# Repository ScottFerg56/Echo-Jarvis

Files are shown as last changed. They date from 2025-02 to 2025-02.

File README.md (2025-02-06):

# Echo Jarvis
Converting an Amazon Echo Dot housing to contain an ESPHome implementation of Home Assistant voice assist using an ESP32 processor and other electronics devices from Adafruit.
Named after the "Hey Jarvis" wakeword. This is **NOT** a reverse engineering hack of the Echo circuit boards or software, just a repurposing of the sphere housing to contain
several Adafruit electronics parts brought together to make an IoT device for home automation and control. Many others have accomplished the same functionality, housed in
a utilitarian if not aesthetically pleasing 3D-printed box. I wanted something a bit more novel and fun!

## The disassembled Echo Dot:
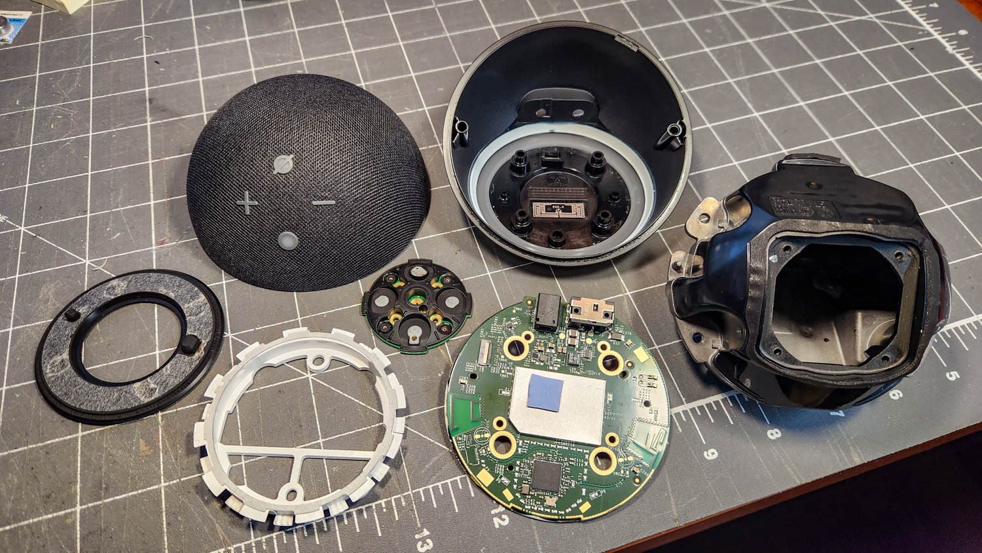
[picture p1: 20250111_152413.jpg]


## Replacement guts:
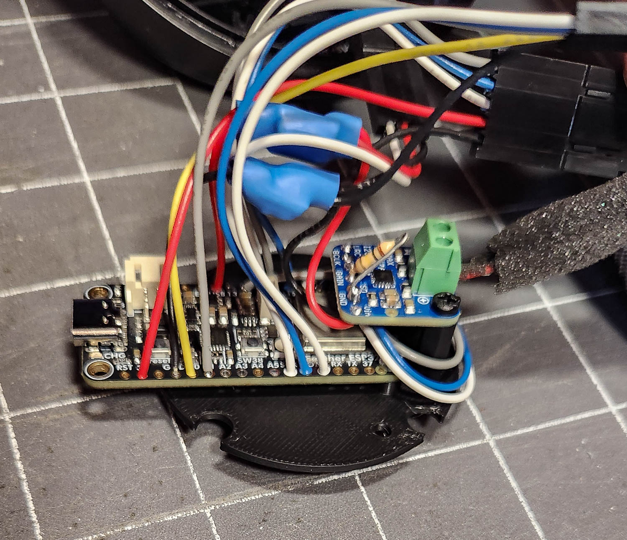
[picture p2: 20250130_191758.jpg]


## The Gallery:
More images and build details are in my [project gallery](https://scottferguson.smugmug.com/Projects/Echo-Jarvis).

## Files:
This project includes the following files:
* Fusion 360 (F3D) files and 3D-printable OBJ files for the button plate and processor mount base plate.
* A spreadsheet with wiring details and parts list with links.
* An image of the wiring details for the processor.
* The YAML file for creating the ESPHome device. This is very basic, but provides a sweet little mechanism for
volume control borrowed from another ESPHome user. (Credits in the file.)

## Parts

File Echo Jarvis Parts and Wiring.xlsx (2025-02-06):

Wiring:
 |  |  | mic 3V
mic GND | neo GND | sw GND | Amp GND
 | Ø | yellow | sw 0
 | O | gray | sw 1
 |  |  |  |  | neo PWR | amp VIN
 |  |  |  |  | amp LRC | gray | strapping
strapping |  |  |  |  | mic DOUT | white
strapping |  |  | neo data |  | mic LRCL | gray
 | + | blue | sw 2 |  | mic BCLK | blue | strapping
 | - | white | sw 3 |  | amp DIN | white
 |  |  |  |  | amp BCLK | blue
Parts:
Adafruit ESP32 Feather V2 (https://www.adafruit.com/product/5400)
Adafruit I2S 3W Class D Amplifier Breakout - MAX98357A (https://www.adafruit.com/product/3006)
Adafruit I2S MEMS Microphone Breakout - SPH0645LM4H (https://www.adafruit.com/product/3421)
Tactile Switch SPST-NO Top Actuated Surface Mount (https://www.digikey.com/en/products/detail/panasonic-electronic-components/EVQ-PPBA25/259539) |  |  |  | no longer manufactured, but equivalent alternatives may exist

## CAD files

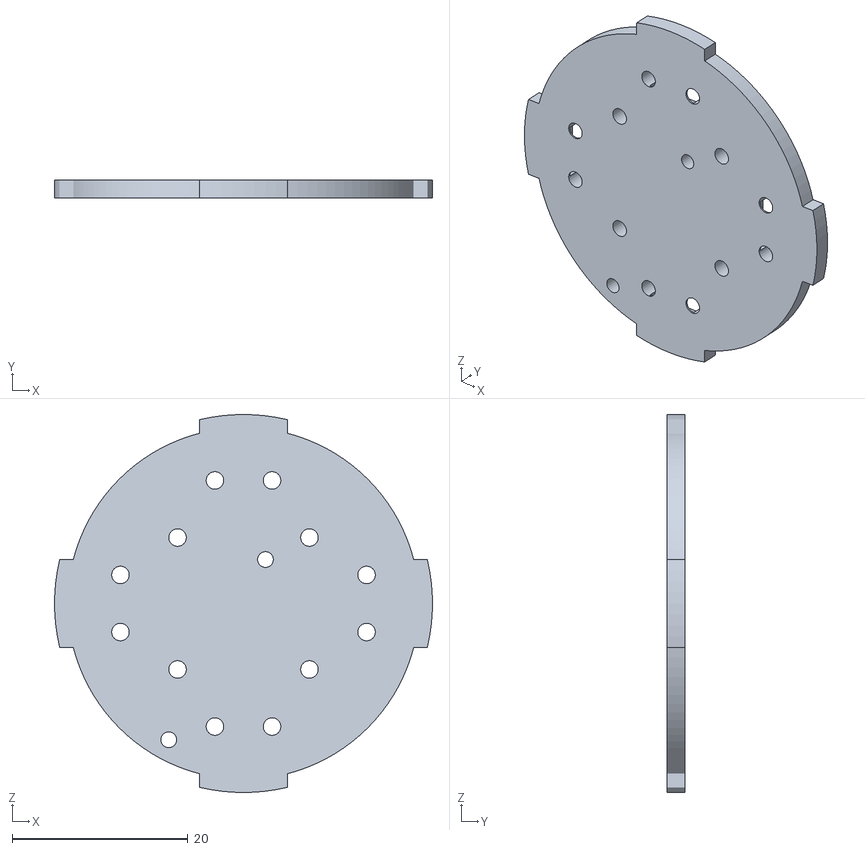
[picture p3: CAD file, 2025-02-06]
Button Plate.obj
43.0 x 2.00 x 43.0

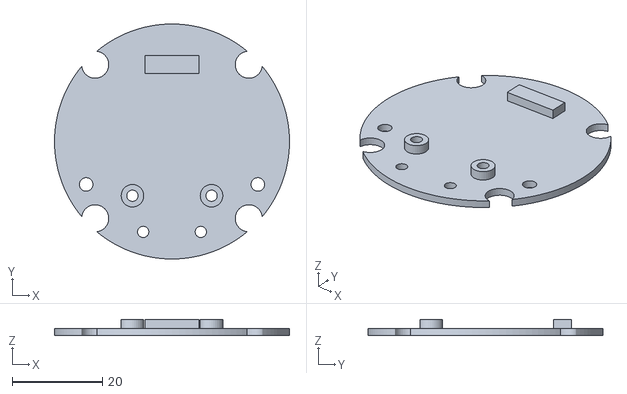
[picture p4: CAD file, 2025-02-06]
Base Plate.obj
52.0 x 52.0 x 3.60

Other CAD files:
Base Plate.f3d
Button Plate.f3d

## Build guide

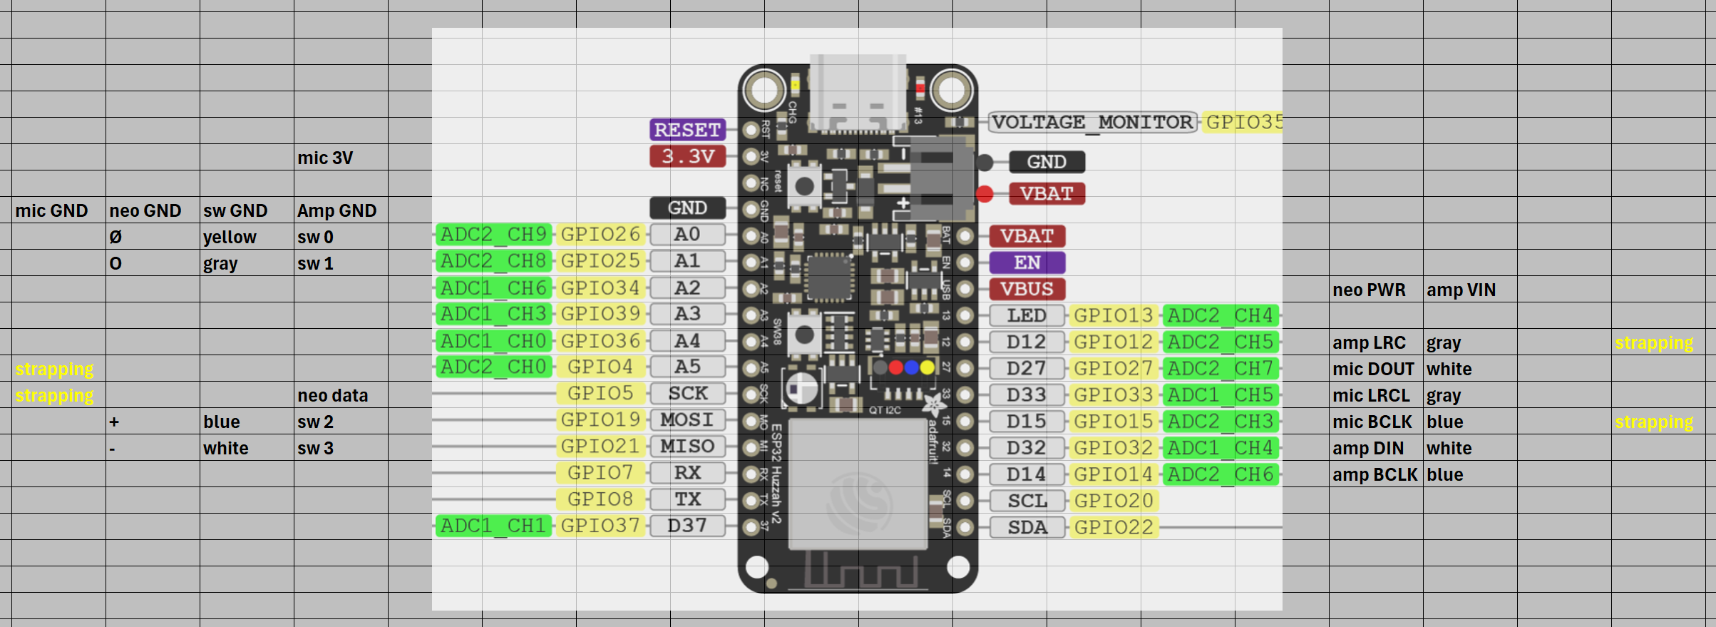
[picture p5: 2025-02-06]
Processor Wiring.png

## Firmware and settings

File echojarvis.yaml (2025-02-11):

esphome:
  name: echojarvis
  friendly_name: EchoJarvis
  on_boot:
    - light.turn_on:
        id: ring_light
        red: 0%
        green: 0%
        blue: 100%
        brightness: 50%

esp32:
  board: adafruit_feather_esp32_v2 # esp32dev
  framework:
    type: esp-idf

# 14:2B:2F:AF:90:F0

# Enable logging
logger:

# Enable Home Assistant API
api:
  encryption:
    key: "***"
  on_client_connected:
        then:
          - delay: 50ms
          - light.turn_off: ring_light
          - micro_wake_word.start:
  on_client_disconnected:
        then:
          - voice_assistant.stop: 

ota:
  - platform: esphome
    password: "***"

wifi:
  ssid: !secret wifi_ssid
  password: !secret wifi_password
  manual_ip:
    static_ip: 192.168.0.201
    gateway: 192.168.0.1
    subnet: 255.255.255.0

  # Enable fallback hotspot (captive portal) in case wifi connection fails
  ap:
    ssid: "Echojarvis Fallback Hotspot"
    password: "***"

captive_portal:

switch:
  - id: offclick
    platform: template
    name: "OffClick"
    optimistic: true
    icon: "mdi:button-pointer"
  - id: onclick
    platform: template
    name: "OnClick"
    optimistic: true
    icon: "mdi:button-pointer"
  - id: plusclick
    platform: template
    name: "PlusClick"
    optimistic: true
    icon: "mdi:button-pointer"
  - id: minusclick
    platform: template
    name: "MinusClick"
    optimistic: true
    icon: "mdi:button-pointer"

binary_sensor:
  - platform: gpio
    id: offbtn
    pin:
      number: GPIO26
      mode: INPUT_PULLUP
      inverted: true
    on_click:
      min_length: 50ms
      max_length: 500ms
      then:
        - switch.turn_on: offclick
        - delay: 500ms
        - switch.turn_off: offclick
  - platform: gpio
    id: onbtn
    pin:
      number: GPIO25
      mode: INPUT_PULLUP
      inverted: true
    on_click:
      min_length: 50ms
      max_length: 500ms
      then:
        - switch.turn_on: onclick
        - delay: 500ms
        - switch.turn_off: onclick
  - platform: gpio
    id: plusbtn
    pin:
      number: GPIO19
      mode: INPUT_PULLUP
      inverted: true
    on_click:
      min_length: 50ms
      max_length: 500ms
      then:
        - switch.turn_on: plusclick
        - delay: 500ms
        - switch.turn_off: plusclick
  - platform: gpio
    id: minusbtn
    pin:
      number: GPIO21
      mode: INPUT_PULLUP
      inverted: true
    on_click:
      min_length: 50ms
      max_length: 500ms
      then:
        - switch.turn_on: minusclick
        - delay: 500ms
        - switch.turn_off: minusclick

light:
  - platform: esp32_rmt_led_strip
    id: ring_light
    chipset: WS2812
    rgb_order: GRB
    pin: GPIO5
    rmt_channel: 0
    num_leds: 24
    name: "Ring Light"
    restore_mode: ALWAYS_OFF
    effects:
      - pulse:
      - pulse:
          name: "Fast Pulse"
          transition_length: 0.5s
          update_interval: 0.5s
      - pulse:
          name: "Slow Pulse"
          transition_length: 500ms
          update_interval: 2s
      - addressable_scan:
      - addressable_scan:
          name: "Scan Wide"
          move_interval: 20ms
          scan_width: 6

i2s_audio:
  - id: i2s_out             # speaker: Adafruit I2S 3W Class D Amplifier Breakout - MAX98357A
    i2s_lrclk_pin: GPIO12   # LRC
    i2s_bclk_pin: GPIO14    # BCLK
  - id: i2s_in              # microphone:
    i2s_lrclk_pin: GPIO33   # LRCL 
    i2s_bclk_pin: GPIO15    # BCLK

microphone:
  - platform: i2s_audio
    id: va_mic
    adc_type: external
    i2s_din_pin: GPIO27     # mic DOUT
    channel: left
    pdm: false
    i2s_audio_id: i2s_in
    bits_per_sample: 32bit
    
speaker:
    platform: i2s_audio
    id: va_speaker
    i2s_audio_id: i2s_out
    dac_type: external
    i2s_dout_pin: GPIO32   #  DIN Pin of the MAX98357A Audio Amplifier
    channel: mono

micro_wake_word:
  on_wake_word_detected:
    - voice_assistant.start:
        wake_word: !lambda return wake_word;
        silence_detection: true
    - light.turn_on:
        id: ring_light
        effect: "Scan Wide"
        red: 0%
        green: 80%
        blue: 0%
        brightness: 80%
  models:
    - model: hey_jarvis

voice_assistant:
  id: va
  microphone: va_mic
  auto_gain: 31dBFS
  noise_suppression_level: 2
  volume_multiplier: 4.0
  speaker: va_speaker
  on_stt_end:
       then: 
         - light.turn_off: ring_light
  on_error:
          - micro_wake_word.start:  
  on_end:
        then:
          - light.turn_off: ring_light
          - wait_until:
              not:
                voice_assistant.is_running:
          - micro_wake_word.start:
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
